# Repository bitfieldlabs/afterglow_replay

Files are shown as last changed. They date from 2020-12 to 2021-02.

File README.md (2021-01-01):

# afterglow replay
The afterglow replay is a mini PCB which can run the attract mode of a Williams Tales of the Arabian Nights pinball machine. It is pure decorative and serves no real purpose :-)
See a video of the board in action:<br>
IMAGE ALT TEXT HERE (https://vimeo.com/493021402)

## Notes
### Power
The board can operate from 3.3V-5V directly.
### Atmega328P
The Atmega328P must be fused as follows: lfuse 0xff, hfuse 0xda, efuse 0xfd.

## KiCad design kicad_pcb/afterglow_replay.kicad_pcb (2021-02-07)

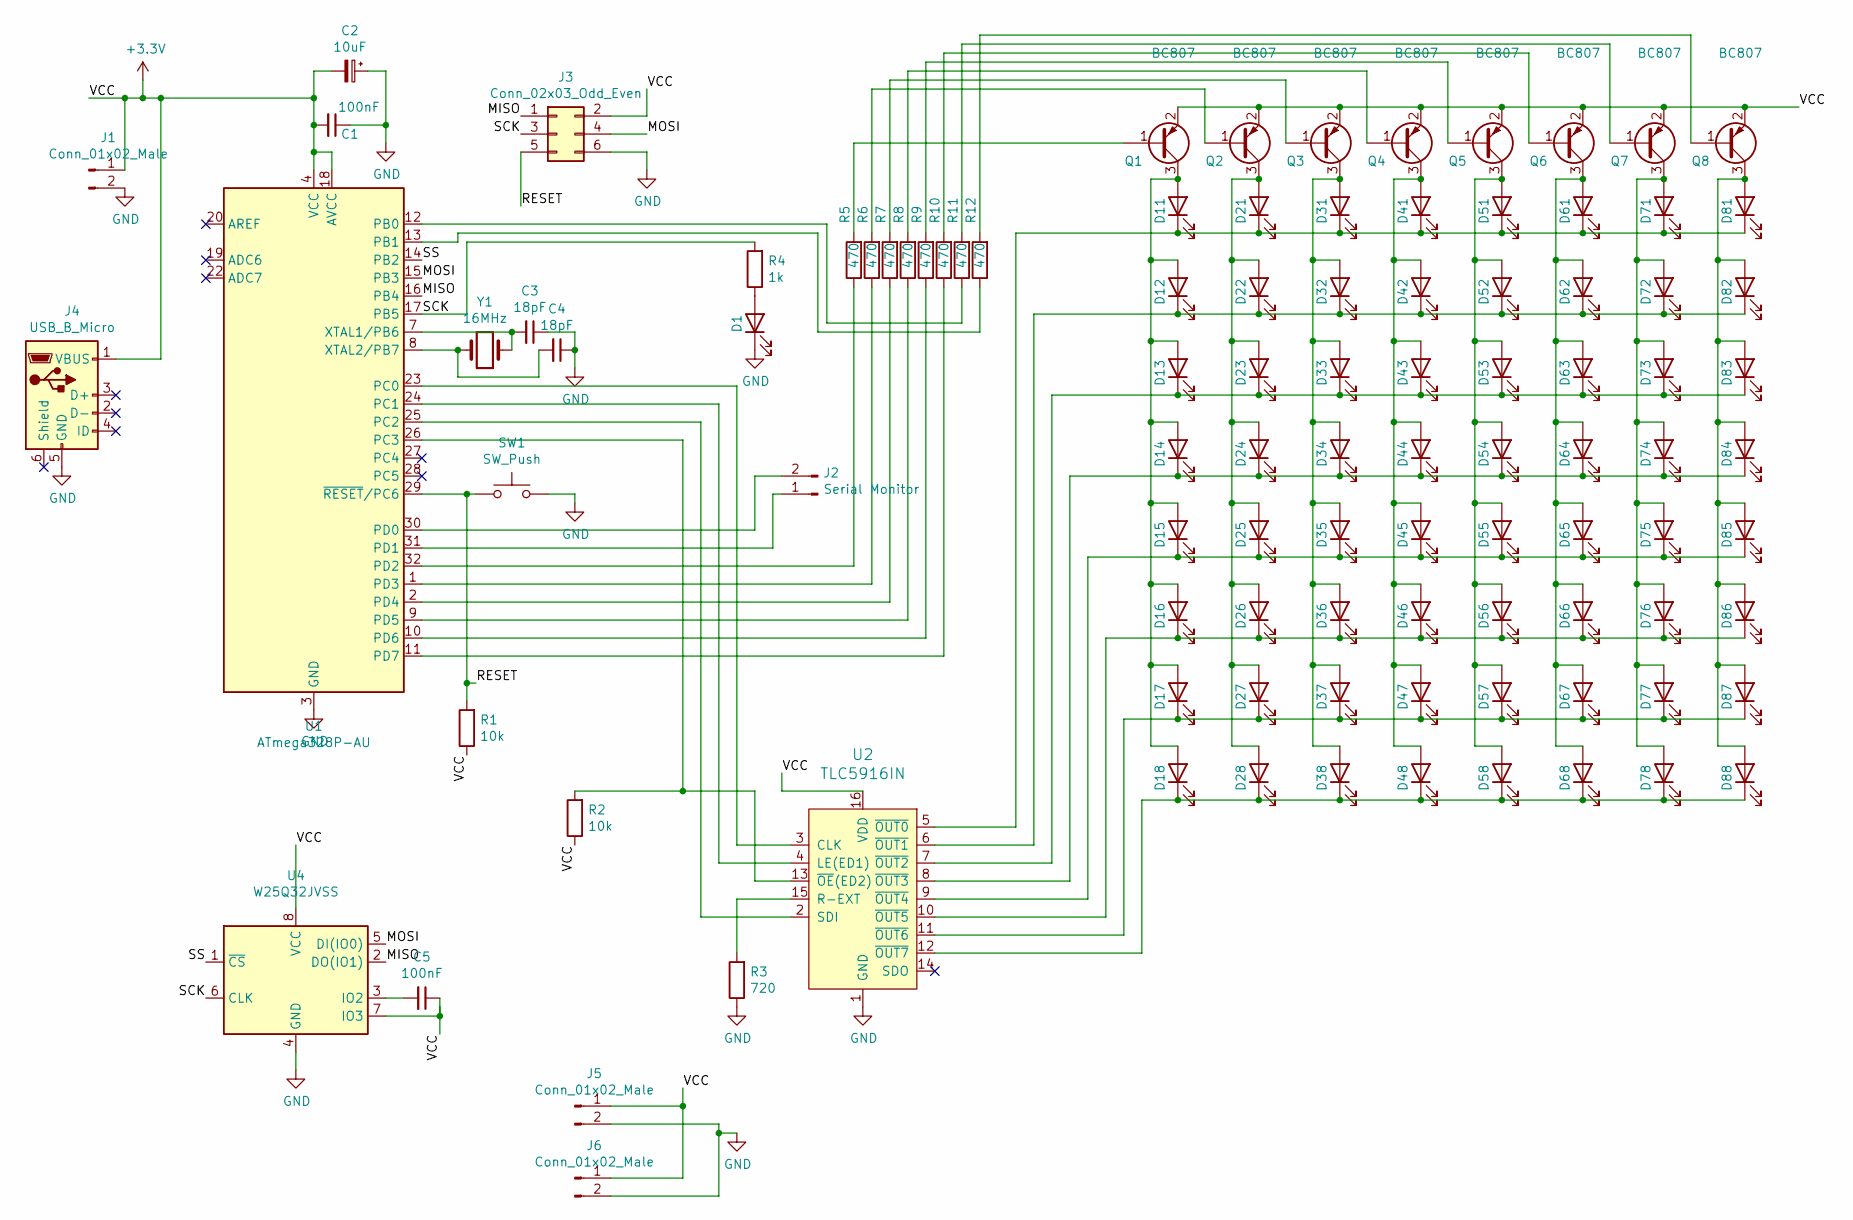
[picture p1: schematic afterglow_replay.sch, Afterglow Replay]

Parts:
C1, C5: 100nF; C_0805_HandSoldering
C2: 10uF; CP_Elec_4x5.3
C3, C4: 18pF; C_0805_HandSoldering
D1, D11, D12, D13, D14, D15, D16, D17, D18, D21, D22, D23, D24, D25, D26, D27, D28, D31, D32, D33, D34, D35, D36, D37, D38, D41, D42, D43, D44, D45, D46, D47, D48, D51, D52, D53, D54, D55, D56, D57, D58, D61, D62, D63, D64, D65, D66, D67, D68, D71, D72, D73, D74, D75, D76, D77, D78, D81, D82, D83, D84, D85, D86, D87, D88: LED; LED_0805_HandSoldering
J1, J5, J6: Conn_01x02_Male; Pin_Header_Straight_1x02_Pitch2.54mm
J2: Serial Monitor; Pin_Header_Straight_1x02_Pitch2.54mm
J3: Conn_02x03_Odd_Even; Pin_Header_Straight_2x03_Pitch2.54mm
J4: USB_B_Micro; USB_Micro-B_Molex-105017-0001
Q1, Q2, Q3, Q4, Q5, Q6, Q7, Q8: BC807; SOT-23_Handsoldering
R1, R2: 10k; R_0805_HandSoldering
R3: 720; R_0805_HandSoldering
R4: 1k; R_0805_HandSoldering
R5, R6, R7, R8, R9, R10, R11, R12: 470; R_0805_HandSoldering
SW1: SW_Push; Panasonic_EVQPUK_EVQPUB
U1: ATmega328P-AU; TQFP-32_7x7mm_Pitch0.8mm
U2: TLC5916IN; SOIC-16_3.9x9.9mm_Pitch1.27mm; MPN TLC5916IN; Digi-Key_PN 296-24383-5-ND
U4: W25Q32JVSS; SOIJ-8_5.3x5.3mm_Pitch1.27mm
Y1: 16MHz; Crystal_SMD_0603-2pin_6.0x3.5mm_HandSoldering

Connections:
+3V3: C1.2, C2.2, C5.1, J1.1, J3.2, J4.1 (VBUS), J5.1, J6.1, Q1.2 (E), Q2.2 (E), Q3.2 (E), Q4.2 (E), Q5.2 (E), Q6.2 (E), Q7.2 (E), Q8.2 (E), R1.1, R2.1, U1.4 (VCC), U1.6 (VCC), U1.18 (AVCC), U2.16 (VDD), U4.7 (IO3), U4.8 (VCC)
/MISO: J3.1, U1.16 (PB4), U4.2 (DO(IO1))
/MOSI: J3.4, U1.15 (PB3), U4.5 (DI(IO0))
/RESET: J3.5, R1.2, SW1.1, U1.29 (~RESET~/PC6)
/SCK: J3.3, R4.2, U1.17 (PB5), U4.6 (CLK)
/SS: U1.14 (PB2), U4.1 (~CS)
GND: C1.1, C2.1, C3.1, C4.1, D1.1 (K), J1.2, J3.6, J4.5 (GND), J5.2, J6.2, R3.1, SW1.2, U1.3 (GND), U1.5 (GND), U1.21 (GND), U2.1 (GND), U4.4 (GND)
unnamed: C3.2, U1.7 (XTAL1/PB6), Y1.1
unnamed: C4.2, U1.8 (XTAL2/PB7), Y1.2
unnamed: C5.2, U4.3 (IO2)
unnamed: D1.2 (A), R4.1
unnamed: D11.1 (K), D21.1 (K), D31.1 (K), D41.1 (K), D51.1 (K), D61.1 (K), D71.1 (K), D81.1 (K), U2.5 (~OUT0)
unnamed: D11.2 (A), D12.2 (A), D13.2 (A), D14.2 (A), D15.2 (A), D16.2 (A), D17.2 (A), D18.2 (A), Q1.3 (C)
unnamed: D12.1 (K), D22.1 (K), D32.1 (K), D42.1 (K), D52.1 (K), D62.1 (K), D72.1 (K), D82.1 (K), U2.6 (~OUT1)
unnamed: D13.1 (K), D23.1 (K), D33.1 (K), D43.1 (K), D53.1 (K), D63.1 (K), D73.1 (K), D83.1 (K), U2.7 (~OUT2)
unnamed: D14.1 (K), D24.1 (K), D34.1 (K), D44.1 (K), D54.1 (K), D64.1 (K), D74.1 (K), D84.1 (K), U2.8 (~OUT3)
unnamed: D15.1 (K), D25.1 (K), D35.1 (K), D45.1 (K), D55.1 (K), D65.1 (K), D75.1 (K), D85.1 (K), U2.9 (~OUT4)
unnamed: D16.1 (K), D26.1 (K), D36.1 (K), D46.1 (K), D56.1 (K), D66.1 (K), D76.1 (K), D86.1 (K), U2.10 (~OUT5)
unnamed: D17.1 (K), D27.1 (K), D37.1 (K), D47.1 (K), D57.1 (K), D67.1 (K), D77.1 (K), D87.1 (K), U2.11 (~OUT6)
unnamed: D18.1 (K), D28.1 (K), D38.1 (K), D48.1 (K), D58.1 (K), D68.1 (K), D78.1 (K), D88.1 (K), U2.12 (~OUT7)
unnamed: D21.2 (A), D22.2 (A), D23.2 (A), D24.2 (A), D25.2 (A), D26.2 (A), D27.2 (A), D28.2 (A), Q2.3 (C)
unnamed: D31.2 (A), D32.2 (A), D33.2 (A), D34.2 (A), D35.2 (A), D36.2 (A), D37.2 (A), D38.2 (A), Q3.3 (C)
unnamed: D41.2 (A), D42.2 (A), D43.2 (A), D44.2 (A), D45.2 (A), D46.2 (A), D47.2 (A), D48.2 (A), Q4.3 (C)
unnamed: D51.2 (A), D52.2 (A), D53.2 (A), D54.2 (A), D55.2 (A), D56.2 (A), D57.2 (A), D58.2 (A), Q5.3 (C)
unnamed: D61.2 (A), D62.2 (A), D63.2 (A), D64.2 (A), D65.2 (A), D66.2 (A), D67.2 (A), D68.2 (A), Q6.3 (C)
unnamed: D71.2 (A), D72.2 (A), D73.2 (A), D74.2 (A), D75.2 (A), D76.2 (A), D77.2 (A), D78.2 (A), Q7.3 (C)
unnamed: D81.2 (A), D82.2 (A), D83.2 (A), D84.2 (A), D85.2 (A), D86.2 (A), D87.2 (A), D88.2 (A), Q8.3 (C)
unnamed: J2.1, U1.31 (PD1)
unnamed: J2.2, U1.30 (PD0)
unnamed: Q1.1 (B), R5.2
unnamed: Q2.1 (B), R6.2
unnamed: Q3.1 (B), R7.2
unnamed: Q4.1 (B), R8.2
unnamed: Q5.1 (B), R9.2
unnamed: Q6.1 (B), R10.2
unnamed: Q7.1 (B), R11.2
unnamed: Q8.1 (B), R12.2
unnamed: R2.2, U1.26 (PC3), U2.13 (~OE~(ED2))
unnamed: R3.2, U2.15 (R-EXT)
unnamed: R5.1, U1.32 (PD2)
unnamed: R6.1, U1.1 (PD3)
unnamed: R7.1, U1.2 (PD4)
unnamed: R8.1, U1.9 (PD5)
unnamed: R9.1, U1.10 (PD6)
unnamed: R10.1, U1.11 (PD7)
unnamed: R11.1, U1.12 (PB0)
unnamed: R12.1, U1.13 (PB1)
unnamed: U1.23 (PC0), U2.3 (CLK)
unnamed: U1.24 (PC1), U2.4 (LE(ED1))
unnamed: U1.25 (PC2), U2.2 (SDI)

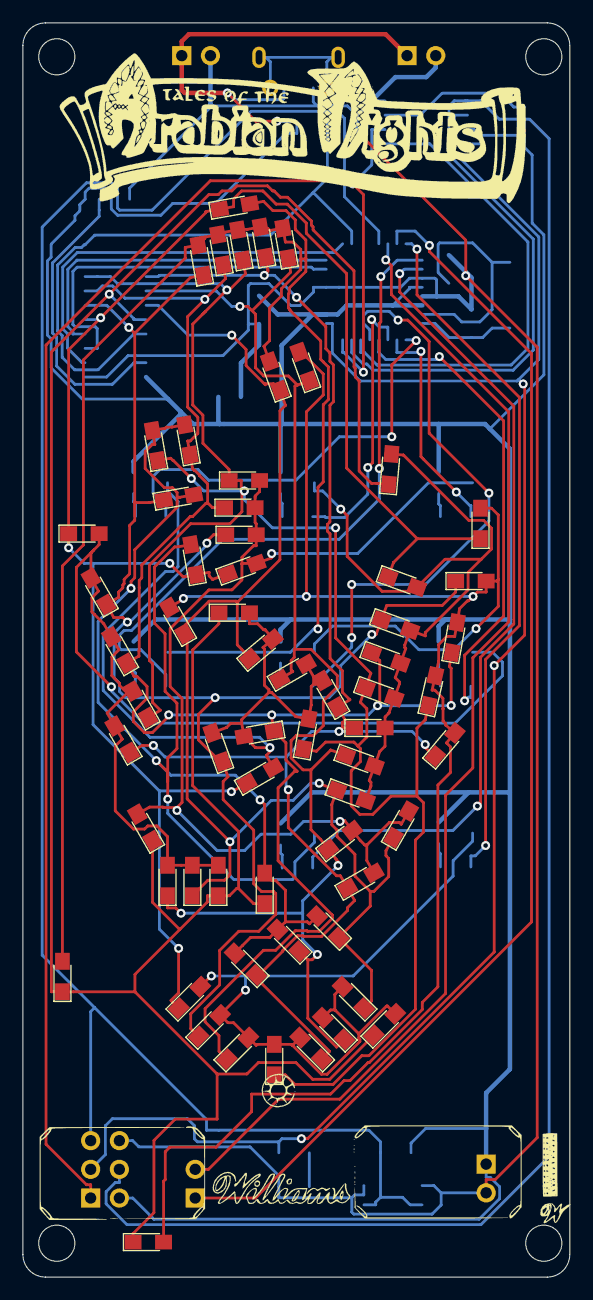
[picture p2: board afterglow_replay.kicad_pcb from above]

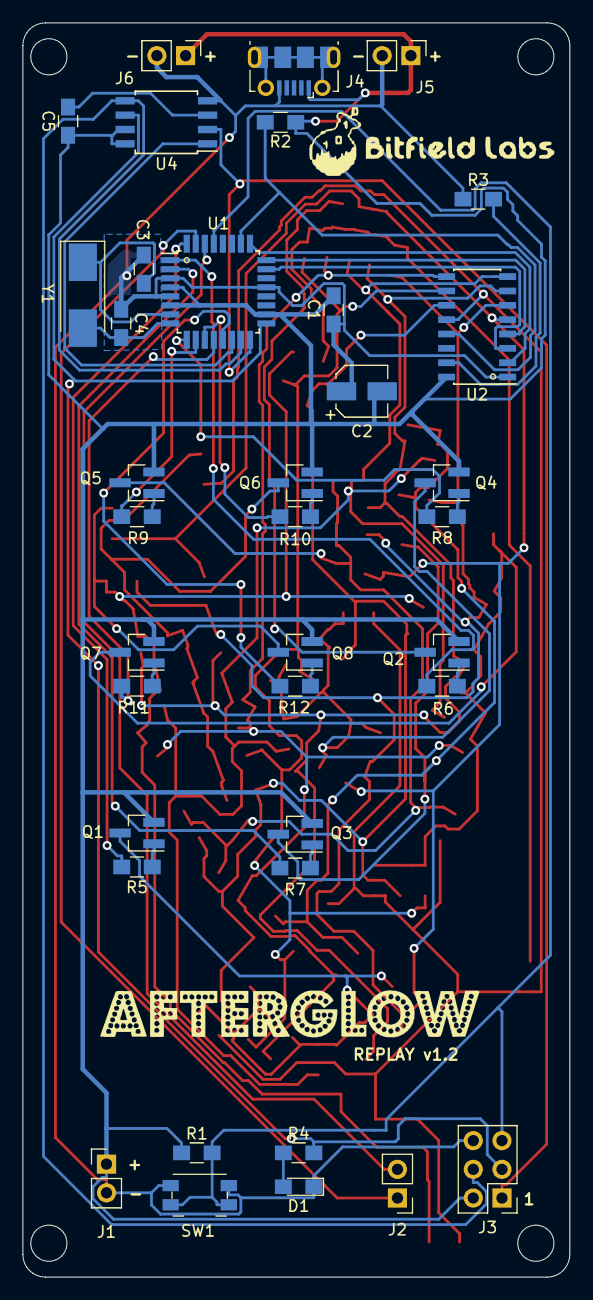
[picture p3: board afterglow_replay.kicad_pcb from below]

Board: 2 copper layers, 48.4 x 111.0 mm, 105 parts (37 on the bottom side), 50 nets.

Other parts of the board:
OL: MountingHole_3.2mm_M3_DIN965
OR: MountingHole_3.2mm_M3_DIN965
PLAYFIELD: LOGO; totan
UL: MountingHole_3.2mm_M3_DIN965

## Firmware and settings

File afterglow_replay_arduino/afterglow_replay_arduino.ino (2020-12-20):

/***********************************************************************
 *  afterglow replay:
 *      Copyright (c) 2020 bitfield labs
 *
 ***********************************************************************
 *  This file is part of the afterglow pinball LED project:
 *  https://github.com/bitfieldlabs/afterglow_replay
 *
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
 *  You should have received a copy of the GNU Lesser General Public
 *  License along with afterglow replay.
 *  If not, see <http://www.gnu.org/licenses/>.
 ***********************************************************************/
 
//------------------------------------------------------------------------------
/* This code assumes following pin layout:
 *
 *  +----------+---------------+-----------+---------------+--------------+
 *  | Name     | Function      | Nano Pin# | Register, Bit | Mode         |
 *  +----------+---------------+-----------+---------------+--------------+
 *  +----------+---------------+-----------+---------------+--------------+
*/

#include <EEPROM.h>
#include <avr/wdt.h>
#include <avr/boot.h>

//------------------------------------------------------------------------------
// Setup

// Afterglow version number
#define AFTERGLOW_REPLAY_VERSION 100

// Afterglow replay board revision. Currently v1.0.
#define BOARD_REV 10

// turn debug output via serial on/off
#define DEBUG_SERIAL 0

// original matrix update interval [us]
#define ORIG_INT (2000)

// local time interval, config A [us]
#define TTAG_INT_A (250)

// cycles per original interval, config A
#define ORIG_CYCLES_A (ORIG_INT / TTAG_INT_A)

// number of columns in the lamp matrix
#define NUM_COL 8

// number of rows in the lamp matrix
#define NUM_ROW 8

// default glow duration [ms]
#define DEFAULT_GLOWDUR 180

// glow duration scaling in the configuration
#define GLOWDUR_CFG_SCALE 10

// default maximum lamp brightness 0-7
#define DEFAULT_BRIGHTNESS 7

// afterglow LED glow duration [ms]
#define AFTERGLOW_LED_DUR (2000)

// current supervision on pin A0
#define CURR_MEAS_PIN A0

// test mode setup
#define TEST_MODE_NUMMODES 7    // number of test modes
#define TEST_MODE_DUR 8         // test duration per mode [s]
#define TESTMODE_INT (500)      // test mode lamp switch interval [ms]
#define TESTMODE_CYCLES_A ((uint32_t)TESTMODE_INT * 1000UL / (uint32_t)TTAG_INT_A) // number of cycles per testmode interval, config A

// enable lamp replay in test mode
#define REPLAY_ENABLED

#ifdef REPLAY_ENABLED
// Replay time scale [us]
#define REPLAY_TTAG_SCALE 16000

// Replay record
typedef struct AG_LAMP_SWITCH_s
{
    uint16_t col : 3;    // lamp column
    uint16_t row : 3;    // lamp row
    uint16_t dttag : 10; // delta time tag [16ms] to the last event
} AG_LAMP_SWITCH_t;

// Replay logic
byte replay(void);

// Number of replay records
int numReplays(void);
#endif // REPLAY_ENABLED


//------------------------------------------------------------------------------
// global variables

// Lamp matrix 'memory'
static uint16_t sMatrixState[NUM_COL][NUM_ROW];
    
// local time
static uint32_t sTtag = 0;

// interrupt runtime counters [cycles]
static uint16_t sLastIntTime = 0;
static uint16_t sMaxIntTime = 0;

// remember the last column and row samples
static byte sLastColMask = 0;
static byte sLastRowMask = 0;

#if DEBUG_SERIAL
static byte sLastOutColMask = 0;
static byte sLastOutRowMask = 0;
static uint32_t sBadColCounter = 0;
static uint32_t sBadColOrderCounter = 0;
static byte sLastBadCol = 0;
static byte sLastGoodCol = 0;
static int sMaxCurr = 0;
static int sLastCurr = 0;
#endif

// afterglow configuration data definition
typedef struct AFTERGLOW_CFG_s
{
    uint16_t version;                         // afterglow version of the configuration
    uint16_t res;                             // reserved bytes
    uint8_t lampGlowDur[NUM_COL][NUM_ROW];    // Lamp matrix glow duration configuration [ms * GLOWDUR_CFG_SCALE]
    uint8_t lampBrightness[NUM_COL][NUM_ROW]; // Lamp matrix maximum brightness configuration (0-7)
    uint32_t crc;                             // data checksum
} AFTERGLOW_CFG_t;

// afterglow configuration
static AFTERGLOW_CFG_t sCfg;

// precalculated glow steps for each lamp
static uint16_t sGlowSteps[NUM_COL][NUM_ROW];

// precalculated maximum subcycle for lamp activation (brightness)
static byte sMaxSubcycle[NUM_COL][NUM_ROW];


//------------------------------------------------------------------------------
void setup()
{
    noInterrupts(); // disable all interrupts

    // setup the timers
    timerSetup();

    // I/O pin setup
    DDRB |= B00000011;
    DDRC |= B00001111;
    DDRD |= B11111110;
    
    // keep OE high for now
    PORTC |= B00001000;

    // Configure the ADC clock to 1MHz by setting the prescaler to 16.
    // This should allow for fast analog pin sampling without much loss of precision.
    // defines for setting and clearing register bits.
    _SFR_BYTE(ADCSRA) |= _BV(ADPS2);
    _SFR_BYTE(ADCSRA) &= ~_BV(ADPS1);
    _SFR_BYTE(ADCSRA) &= ~_BV(ADPS0);

    // initialize the data
    memset(sMatrixState, 0, sizeof(sMatrixState));

    // set default configuration
    setDefaultCfg();

    // Apply the configuration
    // This will prepare all values for the interrupt handlers.
    applyCfg();

    // enable serial output at 115200 baudrate
#if DEBUG_SERIAL
    Serial.begin(115200);
    Serial.print("afterglow replay v");
    Serial.print(AFTERGLOW_REPLAY_VERSION);
    Serial.println(" (c) 2018 morbid cornflakes");
    // check the extended fuse for brown out detection level
    uint8_t efuse = boot_lock_fuse_bits_get(GET_EXTENDED_FUSE_BITS);
    Serial.println("-----------------------------------------------");
    uint8_t bodBits = (efuse & 0x7);
    Serial.print("efuse BOD ");
    Serial.println((bodBits == 0x07) ? "OFF" : (bodBits == 0x04) ? "4.3V" : (bodBits == 0x05) ? "2.7V" : "1.8V");
#ifdef REPLAY_ENABLED
    Serial.print("Replay Table Size: ");
    Serial.println(numReplays());
#endif
    Serial.print("CFG from ");
    Serial.print(cfgLoaded ? "EEPROM" : "DEFAULT");
    if (err)
    {
        Serial.print(" err ");
        Serial.print(err);
    }
    Serial.println("");
#endif

    // enable all interrupts
    interrupts();

    // enable a strict 15ms watchdog
    wdt_enable(WDTO_15MS);
}

//------------------------------------------------------------------------------
void timerSetup(void)
{
    // Use Timer1 to create an interrupt every TTAG_INT us.
    // This will be the heartbeat of our realtime task.
    TCCR1A = 0;
    TCCR1B = 0;
    // set compare match register for TTAG_INT us increments
    // prescaler is at 1, so counting real clock cycles
    OCR1A = (TTAG_INT_A * 16);   // [16MHz clock cycles]
    // turn on CTC mode
    TCCR1B |= (1 << WGM12);
    // Set CS10 bit so timer runs at clock speed
    TCCR1B |= (1 << CS10);  
    // enable timer compare interrupt
    TIMSK1 |= (1 << OCIE1A);
}

//------------------------------------------------------------------------------
void start()
{
    // enable the timer compare interrupt
    TIMSK1 |= (1 << OCIE1A);

    // enable a strict 15ms watchdog
    wdt_enable(WDTO_15MS);
}

//------------------------------------------------------------------------------
void stop()
{
    // disable the watchdog
    wdt_disable();

    // disable the timer compare interrupt
    TIMSK1 &= ~(1 << OCIE1A);

    // pull OE high to disable all outputs
    PORTC |= B00001000;
}

//------------------------------------------------------------------------------
// Timer1 interrupt handler
// This is the realtime task heartbeat. All the magic happens here.
ISR(TIMER1_COMPA_vect)
{   
    // time is running
    uint16_t startCnt = TCNT1;
    sTtag++;

    // kick the dog
    wdt_reset();

    // afterglow mode
    driveLampMatrix();

    // replay mode
    uint16_t inData = testModeInput();

    byte inColMask = (inData >> 8); // LSB is col 0, MSB is col 7
    byte inRowMask = ~(byte)inData; // high means OFF, LSB is row 0, MSB is row 7

    // evaluate the column reading
    // only one bit should be set as only one column can be active at a time
    uint32_t inCol = NUM_COL;
    switch (inColMask)
    {
        case 0x01: inCol = 0; break;
        case 0x02: inCol = 1; break;
        case 0x04: inCol = 2; break;
        case 0x08: inCol = 3; break;
        case 0x10: inCol = 4; break;
        case 0x20: inCol = 5; break;
        case 0x40: inCol = 6; break;
        case 0x80: inCol = 7; break;
        default:
        {
            // This may happen if the sample is taken in between column transition.
            // Depending on the pinball ROM version the duration of this transition varies.
            // On a Whitewater with Home ROM LH6 (contains anti ghosting updates) this
            // gap was measured to be around 30us long.
            // Machines with anti-ghosting firmware will show a gap with no column enabled
            // for a while during the transition while older firmwares might have two
            // columns enabled at the same time due to slow transistor deactivation. Both
            // cases are caught here.
            // See also https://emmytech.com/arcade/led_ghost_busting/index.html for details.
#if DEBUG_SERIAL
            sBadColCounter++;
            sLastBadCol = inColMask;
#endif
        }
        break;
    }

    // update the current column
    updateCol(inCol, inRowMask);

#if DEBUG_SERIAL
    if ((inCol != (sLastGoodCol+1)) && (inCol!=(sLastGoodCol-7)))
    {
        sBadColOrderCounter++;
    }
    sLastGoodCol = inCol;
#endif

    // remember the last column and row samples
    sLastColMask = inColMask;
    sLastRowMask = inRowMask;

    // how long did it take?
    sLastIntTime = (TCNT1 - startCnt);
    if ((sLastIntTime > sMaxIntTime) && (sLastIntTime < (1000 * 16)))
    {
        sMaxIntTime = sLastIntTime;
    }
}

//------------------------------------------------------------------------------
void loop()
{
    // The main loop is used for low priority serial communication only.
    // All the lamp matrix fun happens in the timer interrupt.

    // count the loops (used for debug output below)
    static uint32_t loopCounter = 0;
    loopCounter++;

#if DEBUG_SERIAL
    if ((loopCounter % 10) == 0)
    {
        Serial.println("REPLAY!");
        if (0)
        {
            Serial.println("PASS THROUGH!");
        }
        Serial.print("TTAG_INT ");
        Serial.println(TTAG_INT_A);
        Serial.print("INT dt max ");
        Serial.print(sMaxIntTime / 16);
        Serial.print("us last ");
        Serial.print(sLastIntTime / 16);
        Serial.println("us");
        Serial.print("Bad col: ");
        Serial.print(sBadColCounter);
        Serial.print(" col ");
        Serial.print(sLastBadCol);
        Serial.print(" ord ");
        Serial.print(sBadColOrderCounter);
        Serial.print(" last good: ");
        Serial.println(sLastGoodCol);
        Serial.print("CM ");
        Serial.print(sLastCurr);
        Serial.print(" max ");
        Serial.println(sMaxCurr);
        // data debugging
        debugInputs(sLastColMask, sLastRowMask);
        debugOutput(sLastOutColMask, sLastOutRowMask);
        // dump the full matrix
        for (uint32_t c=0; c<NUM_COL; c++)
        {
            Serial.print("C");
            Serial.print(c);
            Serial.print(" + ");
            for (uint32_t r=0; r<NUM_ROW; r++)
            {
                Serial.print(sMatrixState[c][r]);
                Serial.print(" ");
            }
            Serial.println("");
        }
    }
#endif

    // wait 500ms
    delay(500);
}

//------------------------------------------------------------------------------
inline void updateMx(uint16_t *pMx, bool on, uint16_t step)
{
    if (on)
    {
        // increase the stored brightness value
        if (*pMx < (65535 - step))
        {
            *pMx += step;
        }
        else
        {
            *pMx = 0xffff;
        }
    }
    else
    {
        // decrease the stored brightness value
        if (*pMx > step)
        {
            *pMx -= step;
        }
        else
        {
            *pMx = 0;
        }
    }
}

//------------------------------------------------------------------------------
void updateCol(uint32_t col, byte rowMask)
{
    // paranoia check
    if (col >= NUM_COL)
    {
        return;
    }
    
    // get a pointer to the matrix column
    uint16_t *pMx = &sMatrixState[col][0];
    const uint16_t *pkStep = &sGlowSteps[col][0];

    // update all row values
    for (uint32_t r=0; r<NUM_ROW; r++)
    {
        // update the matrix value
        updateMx(pMx, (rowMask & 0x01), *pkStep);

        // next row
        pMx++;
        pkStep++;
        rowMask >>= 1;
    }
}

//------------------------------------------------------------------------------
void driveLampMatrix()
{   
    // turn off everything briefly to avoid ghosting
    // the scope says this takes ~20us at 16MHz
    dataOutput(0x00, 0x00);

    // check which column we're currently updating
    uint32_t outCol = (sTtag % NUM_COL);

    // The original cycle is divided into ORIG_CYCLES column sub cycles.
    // These cycles are used to do PWM in order to adjust the lamp brightness.
    //
    // Illustration with ORIG_CYCLES==4 and four brightness steps B1-B4 and off (B0):
    //
    // * Lamp on
    //                      2ms 2ms ...
    // Orig col            1   2   3   4   5   6   7   8   1   2   3   4   5   6
    // afterglow col       12345678123456781234567812345678123456781234567812345
    // col cycle           1       2       3       4       1       2       3
    //
    // Brightness 1        *                               *
    // Brightness 2        *       *                       *       *
    // Brightness 3        *       *       *               *       *       *
    // Brightness 4        *       *       *       *       *       *       *

    uint32_t colCycle = ((sTtag / NUM_COL) % ORIG_CYCLES_A);

    // prepare the data
    // LSB is row/col 0, MSB is row/col 7
    byte colData = (1 << outCol);
    byte rowData = 0;
    uint16_t *pMx = &sMatrixState[outCol][0];
    byte *pMaxSubCycle = &sMaxSubcycle[outCol][0];
    for (uint32_t r=0; r<NUM_ROW; r++)
    {
        // make room for the next bit
        rowData >>= 1;
        
        // nothing to do if the matrix value is zero (off)
        if (*pMx)
        {
            uint16_t subCycle = (*pMx / (65536 / ORIG_CYCLES_A));

            // limit to the configured maximum brightness
            if (subCycle > *pMaxSubCycle)
            {
                subCycle = *pMaxSubCycle;
            }

            // Lamps are turned on when the value in the matrix is not zero
            // and when the value is high enough for the current sub cycle.
            if (subCycle >= colCycle)
            {
                rowData |= 0x80;
            }
        }
        pMx++;
        pMaxSubCycle++;
    }

    // output the data
    dataOutput(colData, rowData);
#if DEBUG_SERIAL
    sLastOutColMask = colData;
    sLastOutRowMask = rowData;
#endif
}

//------------------------------------------------------------------------------
void dataOutput(byte colData, byte rowData)
{
    // disable all columns (PD2-PD7, PB0-PB1) by pulling the ATMEGA pins high
    PORTD |= B11111100;
    PORTB |= B00000011;

    // pull LE and CLK low to start sending data
    PORTC &= B11111100;

    // clock out the shift register
    for (uint8_t bitMask=0x80; bitMask>0; bitMask>>=1)
    {
        PORTC &= B11111110; // CLK low
        if (rowData & bitMask)
        {
            PORTC |= B00000100; // set data bit
        }
        else
        {
            PORTC &= B11111011; // clear data bit
        }
        PORTC |= B00000001; // CLK high
    }

    PORTC &= B11111110; // CLK low

    // pull LE high to latch the data
    PORTC |= B00000010;

    // Enable by pulling OE low.
    // This is only done here to ensure that the LEDs are not turned on before
    // the columns are duty cycled.
    PORTC &= B11110111;

    // enable the column
    if (colData < 0B01000000)
    {
        PORTD &= ~(colData << 2);
    }
    else
    {
        PORTB &= ~(colData >> 6);
    }

    // pull LE low again
    PORTC &= B11111101;
}

//------------------------------------------------------------------------------
uint16_t testModeInput(void)
{
    // simulate the original column cycle
    byte col = ((sTtag / ORIG_CYCLES_A) % NUM_COL);
    byte colMask = (1 << col);

    // populate the row
    byte rowMask = 0;

#ifdef REPLAY_ENABLED
    // replay from table
    rowMask = replay(col);
#endif

    // invert the row mask as in the original input HIGH means off
    rowMask = ~rowMask;

    return ((colMask << 8) | rowMask);
}

//------------------------------------------------------------------------------
void applyCfg()
{
    // calculate the glow steps and maximum subcycles
    uint16_t *pGS = &sGlowSteps[0][0];
    uint8_t *pGlowDur = &sCfg.lampGlowDur[0][0];
    uint8_t *pBrightness = &sCfg.lampBrightness[0][0];
    byte *pMaxSubCycle = &sMaxSubcycle[0][0];
    for (byte c=0; c<NUM_COL; c++)
    {
        for (byte r=0; r<NUM_COL; r++)
        {
            // brightness step per lamp matrix update (assumes one update per original matrix step)
            uint32_t glowDur = (*pGlowDur * GLOWDUR_CFG_SCALE);
            *pGS++ = (glowDur > 0) ?
                ((uint16_t)(65535 / ((glowDur * 1000) / ORIG_INT)) * NUM_COL) : 0xffff;

            // translate maximum brightness into maximum lamp driving subcycle
            *pMaxSubCycle++ = (*pBrightness >> (8/ORIG_CYCLES_A-1));

            // next
            pGlowDur++;
            pBrightness++;
        }
    }
}

//------------------------------------------------------------------------------
void setDefaultCfg()
{
    // initialize configuration to default values
    memset(&sCfg, 0, sizeof(sCfg));
    sCfg.version = 0;
    uint8_t *pGlowDur = &sCfg.lampGlowDur[0][0];
    uint8_t *pBrightness = &sCfg.lampBrightness[0][0];
    for (byte c=0; c<NUM_COL; c++)
    {
        for (byte r=0; r<NUM_ROW; r++)
        {
            *pGlowDur++ = (DEFAULT_GLOWDUR / GLOWDUR_CFG_SCALE);
            *pBrightness++ = DEFAULT_BRIGHTNESS;
        }
    }
}

#if DEBUG_SERIAL
//------------------------------------------------------------------------------
void debugInputs(byte inColMask, byte inRowMask)
{
    // output the data
    char msg[64];
    sprintf(msg, "IN C 0x%02X R 0x%02X\n", inColMask, inRowMask);
    Serial.print(msg);
}

//------------------------------------------------------------------------------
void debugOutput(byte outColMask, byte outRowMask)
{
    // output the data
    char msg[64];
    sprintf(msg, "OUT C 0x%02X R 0x%02X\n", outColMask, outRowMask);
    Serial.print(msg);
}
#endif
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

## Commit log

2020-12-19 Tidying up
    [afterglow_replay.kicad_pcb, afterglow_replay.sch]
2020-12-20 Schematic v1.1 fixes the most stupid errors
    [afterglow_replay.sch]
2020-12-30 PCB v1.1
    [afterglow_replay.kicad_pcb]
2021-02-07 PCB v1.2
    [afterglow_replay-B_Cu.gbr, afterglow_replay-B_Mask.gbr, afterglow_replay-B_Paste.gbr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]
2021-02-07 PCB v1.2 slightly less wide
    [afterglow_replay-B_Cu.gbr, afterglow_replay-B_Mask.gbr, afterglow_replay-B_Paste.gbr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]
2021-02-10 Added a kicad project archive

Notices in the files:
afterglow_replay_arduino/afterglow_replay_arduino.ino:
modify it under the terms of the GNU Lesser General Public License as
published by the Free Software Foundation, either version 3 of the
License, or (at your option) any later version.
